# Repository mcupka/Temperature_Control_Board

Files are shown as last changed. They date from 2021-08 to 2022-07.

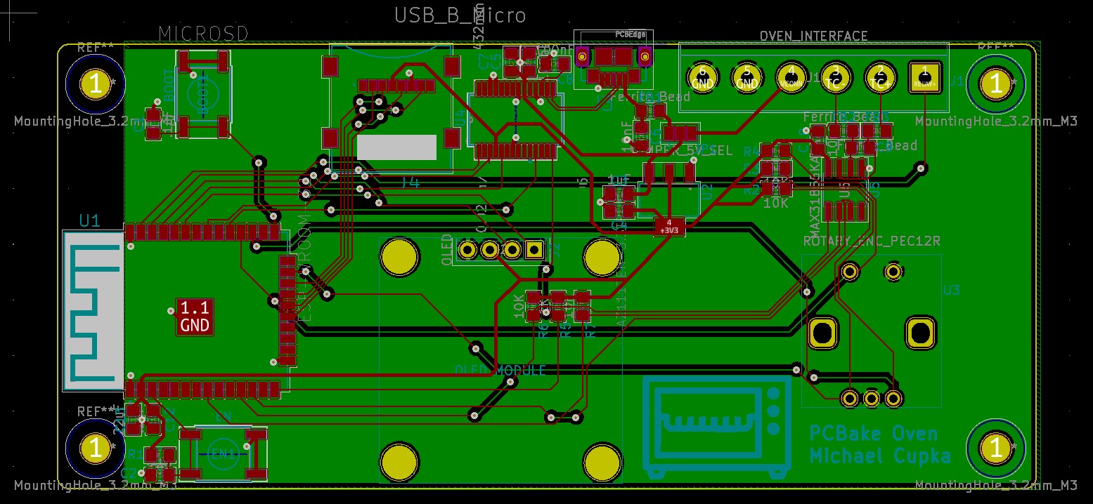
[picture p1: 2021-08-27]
images/v1_0/release_v1_0_pcb.jpg

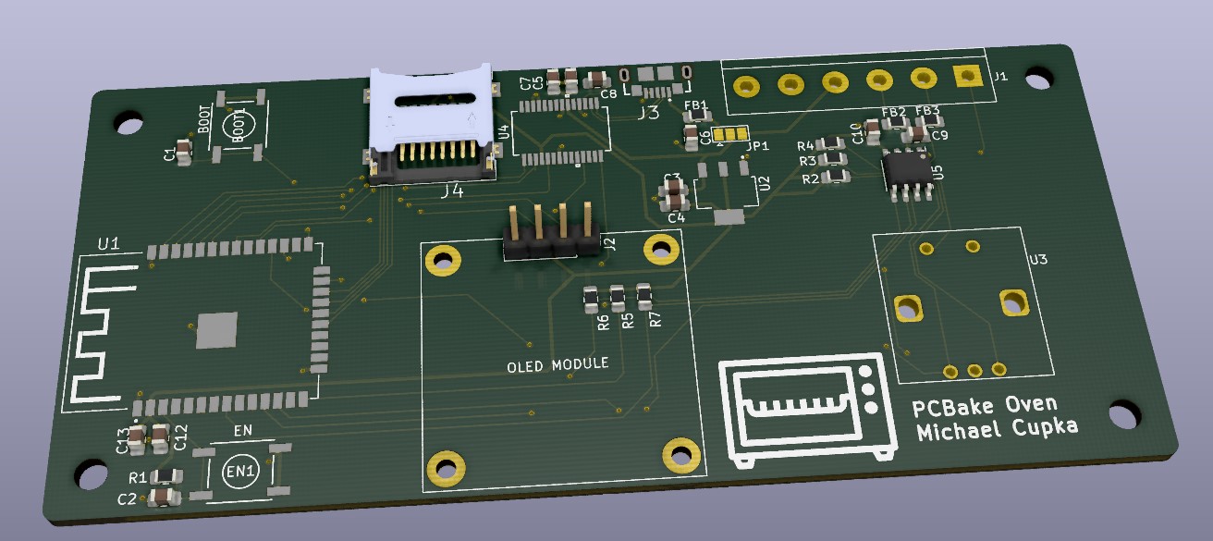
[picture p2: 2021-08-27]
images/v1_0/release_v1_0_render.jpg

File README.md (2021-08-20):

Temperature Control Board

This is a control board for a toaster oven reflow project. It will use the following major parts:

- ESP32 module for processing (wifi / bluetooth maybe?)
- MAX31855 to interface with the thermocouple
- SD Card interface
- I2C interface for OLED display
- UART for debug / programming (microusb?)
- Extra IOs and interfaces available for future uses of this board

Release V1.0 Images:

Release v1.0 PCB Release v1.0 Schematic

Release v1.0 PCB

Release v1.0 PCB Release v1.0 Render

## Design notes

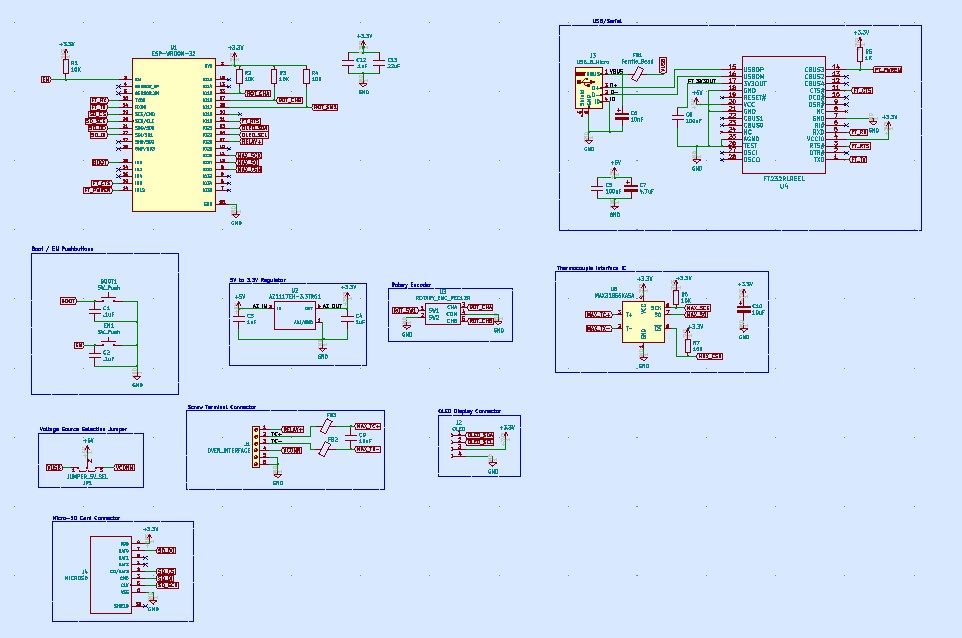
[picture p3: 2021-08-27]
images/v1_0/release_v1_0_sch.jpg

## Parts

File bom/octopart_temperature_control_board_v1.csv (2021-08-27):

Query | Qty | Manufacturer | MPN | Octopart URL | Part Description | Description | Schematic Reference | Internal Part Number | Lifecycle | Lead Time | RoHS | Total Qty (@ Batch Size: 1) | SKU | SKU | SKU | SKU | SKU | Packaging | Packaging | Packaging | Packaging | Packaging | Unit Price (@ Batch Size: 1) | Unit Price (@ Batch Size: 1) | Unit Price (@ Batch Size: 1) | Unit Price (@ Batch Size: 1) | Unit Price (@ Batch Size: 1) | In Stock | In Stock | In Stock | In Stock | In Stock | MOQ | MOQ | MOQ | MOQ | MOQ | URL | URL | URL | URL | URL | Distributor [Lowest Price (Selected)] | SKU [Lowest Price (Selected)] | Packaging [Lowest Price (Selected)] | Unit Price (@ Batch Size: 1) [Lowest Price (Selected)] | Line Total [Lowest Price (Selected)] | Batch Total [Lowest Price (Selected)] | In Stock [Lowest Price (Selected)] | MOQ [Lowest Price (Selected)] | URL [Lowest Price (Selected)] | Notes
 |  |  |  |  |  |  |  |  |  |  |  |  | Digi-Key | Mouser | Newark | Onlinecomponents.com | RS Components | Digi-Key | Mouser | Newark | Onlinecomponents.com | RS Components | Digi-Key | Mouser | Newark | Onlinecomponents.com | RS Components | Digi-Key | Mouser | Newark | Onlinecomponents.com | RS Components | Digi-Key | Mouser | Newark | Onlinecomponents.com | RS Components | Digi-Key | Mouser | Newark | Onlinecomponents.com | RS Components
AZ1117EH-3.3TRG1 | 1 | Diodes Inc. | AZ1117EH-3.3TRG1 | https://octopart.com/az1117eh-3.3trg1-diodes+inc.-49446529 | LDO Fixed Output Voltage Regulator LM3965S-3.3V, +3.3V, 1.5A, SOT223 /tape-2k5/ | 3.3V Regulator | U2 |  |  |  | Compliant | 1
PEC12R-4220F-S0024 | 1 | Bourns | PEC12R-4220F-S0024 | https://octopart.com/pec12r-4220f-s0024-bourns-26648369 | Incremental Encoder 24 PPR 2 Bit Quadrature 5VDC at 10 mA IP40 PCB Mount 100RPM | Rotary Encoder | U3 |  |  | 24w | Compliant | 1 | PEC12R-4220F-S0024-ND | 652-PEC12R-4220F-S24 | 53W9605 | PEC12R-4220F-S0024 | 7377773P | Tray | Tray |  | Bulk |  | 1.17 | 1.15 | 1.15 |  | 1.233 | 7680 | 22 | 51 | 1240 | 1 | 1 | 1 | 1 | 20 | 1 | https://octopart.com/click/track?country=US&ct=offers&ppid=26648369&sid=459&sig=0e801e8&vpid=93845225&ai4=706 | https://octopart.com/click/track?country=US&ct=offers&ppid=26648369&sid=2401&sig=09f0eeb&vpid=84631990&ai4=706 | https://octopart.com/click/track?country=US&ct=offers&ppid=26648369&sid=2402&sig=0076b96&vpid=96067648&ai4=706 | https://octopart.com/click/track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 | https://octopart.com/click/track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 | Newark | 53W9605 |  | 1.15 | 1.15 | 1.15 | 51 | 1 | https://octopart.com/click/track?country=US&ct=offers&ppid=26648369&sid=2402&sig=0076b96&vpid=96067648&ai4=706
OSTTC032162 | 2 | On Shore Technology | OSTTC032162 | https://octopart.com/osttc032162-on+shore+technology-309929 | Terminal Block Header 3 Position Top Screw 0.200" (5.08mm) PC Pins | Screw Terminal Block | J1 |  |  | 17w | Compliant | 2 | ED2610-ND |  |  |  |  | Bulk |  |  |  |  | 0.89 |  |  |  |  | 27826 |  |  |  |  | 1 |  |  |  |  | https://octopart.com/click/track?c=1&country=US&ct=offers&ppid=309929&sid=459&sig=040ab9c&vpid=1686177&ai4=706 |  |  |  |  | Digi-Key | ED2610-ND | Bulk | 0.89 | 1.78 | 1.78 | 27826 | 1 | https://octopart.com/click/track?c=1&country=US&ct=offers&ppid=309929&sid=459&sig=040ab9c&vpid=1686177&ai4=706
MEM2067-02-180-00-A | 1 | Global Connector Technology | MEM2067-02-180-00-A | https://octopart.com/mem2067-02-180-00-a-global+connector+technology-51853453 | 8 Contact Hinged SMT 1.8 mm Profile Micro SD Card (No Peg No Switch) | Micro-SD Card Connector | J4 |  |  |  | Non-Compliant | 1 |  |  | 87X8191 |  |  |  |  |  |  |  |  |  | 1.12 |  |  |  |  | 1000 |  |  |  |  | 1 |  |  |  |  | https://octopart.com/click/track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 |  |  | Newark | 87X8191 |  | 1.12 | 1.12 | 1.12 | 1000 | 1 | https://octopart.com/click/track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
FT232RL-REEL | 1 | FTDI | FT232RL-REEL | https://octopart.com/ft232rl-reel-ftdi-19172117 | USB Controller, 3MBd, USB2.0, 1.8 - 5.25 V, 28-Pin SSOP, USBmadeEZ-UART Series | USB to RS232 controller | U4 |  |  | 33w | Compliant | 1 | 768-1007-6-ND | 895-FT232RL | 91K9918 |  | 406580P | Custom Reel | Tape & Reel |  |  |  | 4.7 | 4.7 | 7.84 |  |  | 0 | 0 | 0 |  | 8387 | 1 | 1 | 1 |  | 20 | https://octopart.com/click/track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 | https://octopart.com/click/track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 | https://octopart.com/click/track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 |  | https://octopart.com/click/track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 | Digi-Key | 768-1007-6-ND | Custom Reel | 4.7 | 4.7 | 4.7 | 0 | 1 | https://octopart.com/click/track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
PTS645SL50SMTR92LFS | 2 | C&K Components | PTS645SL50SMTR92LFS | https://octopart.com/pts645sl50smtr92lfs-c%26k+components-55397153 | Switch Tactile N.O. SPST Round Button Gull Wing 0.05A 12VDC 100000Cycles 1.27N SMD T/R | Tactile Switch | BOOT1, EN1 |  |  | 30w | Compliant | 2 | CKN9088CT-ND | 611-PTS645SL50SMTR92 | 35AH5230 | PTS645SL50SMTR92LFS | 1359177 | Cut Tape | Tape & Reel |  | Bulk |  | 0.25 | 0.26 | 0.166 |  |  | 125100 | 22727 | 437 | 1800 | 1 | 1 | 1 | 1 | 1000 | 1000 | https://octopart.com/click/track?country=US&ct=offers&ppid=55397153&sid=459&sig=0bc7f49&vpid=76879289&ai4=706 | https://octopart.com/click/track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 | https://octopart.com/click/track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 | https://octopart.com/click/track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 | https://octopart.com/click/track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 | Newark | 35AH5230 |  | 0.166 | 0.332 | 0.332 | 437 | 1 | https://octopart.com/click/track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
USB3076-30-A | 1 | Global Connector Technology | USB3076-30-A | https://octopart.com/usb3076-30-a-global+connector+technology-21335114 | Conn Micro USB Type B RCP 2Power/3Signal POS 0.65mm Solder RA SMD 5 Terminal 1 Port T/R | Micro-USB Connector | J3 |  |  |  | Compliant | 1 |  |  | 73T7895 |  |  |  |  |  |  |  |  |  | 0.232 |  |  |  |  | 1341 |  |  |  |  | 1 |  |  |  |  | https://octopart.com/click/track?country=US&ct=offers&ppid=21335114&sid=2402&sig=0acd79c&vpid=44730736&ai4=706 |  |  | Newark | 73T7895 |  | 0.232 | 0.232 | 0.232 | 1341 | 1 | https://octopart.com/click/track?country=US&ct=offers&ppid=21335114&sid=2402&sig=0acd79c&vpid=44730736&ai4=706
ESP32-WROOM-32 | 1 | Espressif Systems | ESP32-WROOM-32 | https://octopart.com/esp32-wroom-32-espressif+systems-91025511 | Bluetooth and Wi-Fi Module 2.4GHz to 2.5GHz 2.7V to 3.6V 38-Pin SMD Module | ESP32 Microcontroller Module | U1 |  |  | 8w | Non-Compliant | 1 | 1904-1010-6-ND |  |  |  |  | Custom Reel |  |  |  |  | 0 |  |  |  |  | 0 |  |  |  |  | 1 |  |  |  |  | https://octopart.com/click/track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 |  |  |  |  | Digi-Key | 1904-1010-6-ND | Custom Reel | 0 | 0 | 0 | 0 | 1 | https://octopart.com/click/track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
MAX31855KASA+T | 1 | Maxim Integrated | MAX31855KASA+T | https://octopart.com/max31855kasa%2Bt-maxim+integrated-18998174 | MAX31855 Series 3.6V 900 uA 470.6 mW Thermocouple-to-Digital Converter - SOIC-8 | Thermocouple Interface IC | U5 |  | Production (Last Updated: 1 month ago) | 52w | Compliant | 1 | MAX31855KASA+TCT-ND | 700-MAX31855KASA+T | 73Y3353 |  | 1904615 | Cut Tape | Tape & Reel |  |  |  | 5.31 | 5.38 | 5.83 |  |  | 4633 | 7895 | 0 |  | 1 | 1 | 1 | 1 |  | 2500 | https://octopart.com/click/track?country=US&ct=offers&ppid=18998174&sid=459&sig=03a4b43&vpid=39491590&ai4=706 | https://octopart.com/click/track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 | https://octopart.com/click/track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 |  | https://octopart.com/click/track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 | Digi-Key | MAX31855KASA+TCT-ND | Cut Tape | 5.31 | 5.31 | 5.31 | 4633 | 1 | https://octopart.com/click/track?country=US&ct=offers&ppid=18998174&sid=459&sig=03a4b43&vpid=39491590&ai4=706
22-28-4360 | 1 | Molex | 22-28-4360 | https://octopart.com/22-28-4360-molex-278204 | KK 254 Breakaway Header, Vertical, 36 Circuits, Tin (Sn) Plating, Mating Pin Length 6.09mm | .1in Pin Header | JP1, J2 |  | Production (Last Updated: 1 year ago) | 14w | Compliant | 1 | WM50014-36-ND | 538-22-28-4360 | 56H2242 | 22-28-4360 | 8967364 | Bulk | Bulk |  | Bulk |  | 1.19 | 1.14 | 1.16 |  |  | 0 | 3393 | 135 | 166 | 1 | 1 | 1 | 1 | 50 | 5 | https://octopart.com/click/track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 | https://octopart.com/click/track?country=US&ct=offers&ppid=278204&sid=2401&sig=07c09e7&vpid=37607153&ai4=706 | https://octopart.com/click/track?country=US&ct=offers&ppid=278204&sid=2402&sig=0a2989d&vpid=2996742&ai4=706 | https://octopart.com/click/track?country=US&ct=offers&ppid=278204&sid=2429&sig=03aef65&vpid=733257100&ai4=706 | https://octopart.com/click/track?country=US&ct=offers&ppid=278204&sid=10022&sig=06d0da3&vpid=575614163&ai4=706 | Mouser | 538-22-28-4360 | Bulk | 1.14 | 1.14 | 1.14 | 3393 | 1 | https://octopart.com/click/track?country=US&ct=offers&ppid=278204&sid=2401&sig=07c09e7&vpid=37607153&ai4=706
STC02SYAN | 1 | Sullins | STC02SYAN | https://octopart.com/stc02syan-sullins-299958 | 2 C, Closed Top, .100" CC; No Mounting, 105 C, PBT; Phos Bronze, 100u" Matte Tin | 1.in Pin Jumper | JP1 |  |  | 5w | Compliant | 1 | S9000-ND |  |  |  |  | Bulk |  |  |  |  | 0.1 |  |  |  |  | 519275 |  |  |  |  | 1 |  |  |  |  | https://octopart.com/click/track?country=US&ct=offers&ppid=299958&sid=459&sig=0070ac5&vpid=1221941&ai4=706 |  |  |  |  | Digi-Key | S9000-ND | Bulk | 0.1 | 0.1 | 0.1 | 519275 | 1 | https://octopart.com/click/track?country=US&ct=offers&ppid=299958&sid=459&sig=0070ac5&vpid=1221941&ai4=706
BLM21PG221SN1D | 3 | Murata | BLM21PG221SN1D | https://octopart.com/blm21pg221sn1d-murata-368353 | Ferrite Beads Multi-Layer 220Ohm 25% 100MHz 2A 45mOhm DCR 0805 Paper T/R | Ferrite Bead | FB1, FB2, FB3 |  | Production (Last Updated: 1 month ago) | 21w | Compliant | 3 | 490-1054-1-ND | 81-BLM21P221SG | 73M9167 |  | 7241532P | Cut Tape | Tape & Reel |  |  |  | 0.11 | 0.1 | 0.15 |  |  | 62249 | 0 | 17183 |  | 1 | 1 | 1 | 1 |  | 25 | https://octopart.com/click/track?country=US&ct=offers&ppid=368353&sid=459&sig=0703c49&vpid=2086687&ai4=706 | https://octopart.com/click/track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 | https://octopart.com/click/track?country=US&ct=offers&ppid=368353&sid=2402&sig=0465cb4&vpid=11380727&ai4=706 |  | https://octopart.com/click/track?country=US&ct=offers&ppid=368353&sid=10022&sig=01d5a40&vpid=660716784&ai4=706 | Mouser | 81-BLM21P221SG | Tape & Reel | 0.1 | 0.30000000000000004 | 0.30000000000000004 | 0 | 1 | https://octopart.com/click/track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
08055C104KAT2A | 5 | AVX | 08055C104KAT2A | https://octopart.com/08055c104kat2a-avx-55386349 | Capacitor, Ceramic; 0.1UF; Chip; Case 0805; +/-10%; 50WVDC; SMD; X7R; 2.5% Df; 0.037IN. , | Capacitor, .1 uF | C1, C2, C5, C8, C12 |  | Production (Last Updated: 2 years ago) | 34w | Compliant | 5 | 478-1395-1-ND | 581-08055C104K | 27C8438 |  | 4646688 | Cut Tape | Tape & Reel |  |  |  | 0.1 | 0.16 | 0.192 |  |  | 6564853 | 2547831 | 249789 |  | 1 | 1 | 1 | 1 |  | 50 | https://octopart.com/click/track?country=US&ct=offers&ppid=55386349&sid=459&sig=01b1845&vpid=187969502&ai4=706 | https://octopart.com/click/track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 | https://octopart.com/click/track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 |  | https://octopart.com/click/track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 | Digi-Key | 478-1395-1-ND | Cut Tape | 0.1 | 0.5 | 0.5 | 6564853 | 1 | https://octopart.com/click/track?country=US&ct=offers&ppid=55386349&sid=459&sig=01b1845&vpid=187969502&ai4=706
CC0805KKX7R7BB105 | 2 | Yageo | CC0805KKX7R7BB105 | https://octopart.com/cc0805kkx7r7bb105-yageo-8376555 | 0805 1 uF 16 V ±10 % Tolerance X7R SMT Multilayer Ceramic Capacitor | Capacitor, 1 uF | C3, C4 |  |  | 24w | Compliant | 2 | 311-1365-1-ND | 603-CC805KKX7R7BB105 | 68R4880 |  | 1988098 | Cut Tape | Tape & Reel |  |  |  | 0.16 | 0.24 | 0.288 |  |  | 649716 | 4808 | 1152 |  | 2300 | 1 | 1 | 1 |  | 100 | https://octopart.com/click/track?country=US&ct=offers&ppid=8376555&sid=459&sig=0a46e44&vpid=34209660&ai4=706 | https://octopart.com/click/track?country=US&ct=offers&ppid=8376555&sid=2401&sig=0d84cf8&vpid=64034544&ai4=706 | https://octopart.com/click/track?country=US&ct=offers&ppid=8376555&sid=2402&sig=0aba7d4&vpid=21911110&ai4=706 |  | https://octopart.com/click/track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 | Digi-Key | 311-1365-1-ND | Cut Tape | 0.16 | 0.32 | 0.32 | 649716 | 1 | https://octopart.com/click/track?country=US&ct=offers&ppid=8376555&sid=459&sig=0a46e44&vpid=34209660&ai4=706
08055C103KAT2A | 2 | AVX | 08055C103KAT2A | https://octopart.com/08055c103kat2a-avx-55388009 | 0805 10 nF 50V ±10% Tolerance X7R Surface Mount Multilayer Ceramic Capacitor | Capacitor, 10 nF | C6, C9 |  | Production (Last Updated: 2 years ago) | 18w | Compliant | 2 | 478-1383-1-ND | 581-08055C103K | 19C6332 |  | 1359020 | Cut Tape | Tape & Reel |  |  |  | 0.1 | 0.14 | 0.168 |  |  | 971967 | 669456 | 110632 |  | 1 | 1 | 1 | 1 |  | 200 | https://octopart.com/click/track?country=US&ct=offers&ppid=55388009&sid=459&sig=0b95265&vpid=187969463&ai4=706 | https://octopart.com/click/track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 | https://octopart.com/click/track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 |  | https://octopart.com/click/track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 | Digi-Key | 478-1383-1-ND | Cut Tape | 0.1 | 0.2 | 0.2 | 971967 | 1 | https://octopart.com/click/track?country=US&ct=offers&ppid=55388009&sid=459&sig=0b95265&vpid=187969463&ai4=706
C0805C226M9PACTU | 1 | KEMET | C0805C226M9PACTU | https://octopart.com/c0805c226m9pactu-kemet-105756 | Multilayer Ceramic Capacitors MLCC - SMD/SMT 22uF 6.3V 0805 RoHS | Capacitor, 22 uF | C13 |  |  | 52w | Compliant | 1 | 399-4696-1-ND | 80-C0805C226M9P | 70K9142 | C0805C226M9PACTU | 6911177 | Cut Tape | Tape & Reel |  | Bulk |  | 0.22 | 1.34 | 0.755 |  |  | 2161537 | 312914 | 5607 | 0 | 1 | 1 | 1 | 1 | 2500 | 25 | https://octopart.com/click/track?country=US&ct=offers&ppid=105756&sid=459&sig=07c97ad&vpid=1861811&ai4=706 | https://octopart.com/click/track?country=US&ct=offers&ppid=105756&sid=2401&sig=05dfd3b&vpid=37686783&ai4=706 | https://octopart.com/click/track?country=US&ct=offers&ppid=105756&sid=2402&sig=0dd61dd&vpid=16452457&ai4=706 | https://octopart.com/click/track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 | https://octopart.com/click/track?country=US&ct=offers&ppid=105756&sid=10022&sig=0fd2a39&vpid=575542129&ai4=706 | Digi-Key | 399-4696-1-ND | Cut Tape | 0.22 | 0.22 | 0.22 | 2161537 | 1 | https://octopart.com/click/track?country=US&ct=offers&ppid=105756&sid=459&sig=07c97ad&vpid=1861811&ai4=706
CL21B475KOFNNNE | 1 | Samsung | CL21B475KOFNNNE | https://octopart.com/cl21b475kofnnne-samsung-19832443 | Cap Ceramic 4.7uF 16V X7R 10% SMD 0805 125°C Emboss T/R | Capacitor, 4.7 uF | C7 |  | Production (Last Updated: 1 year ago) | 28w | Compliant | 1 | 1276-2873-1-ND | 187-CL21B475KOFNNNE | 82AC9465 |  |  | Cut Tape | Tape & Reel |  |  |  | 0.28 | 0.29 | 0.35 |  |  | 196685 | 3572 | 32316 |  |  | 1 | 1 | 1 |  |  | https://octopart.com/click/track?country=US&ct=offers&ppid=19832443&sid=459&sig=0fea03e&vpid=72526665&ai4=706 | https://octopart.com/click/track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 | https://octopart.com/click/track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 |  |  | Digi-Key | 1276-2873-1-ND | Cut Tape | 0.28 | 0.28 | 0.28 | 196685 | 1 | https://octopart.com/click/track?country=US&ct=offers&ppid=19832443&sid=459&sig=0fea03e&vpid=72526665&ai4=706
CC0805KKX5R6BB106 | 1 | Yageo | CC0805KKX5R6BB106 | https://octopart.com/cc0805kkx5r6bb106-yageo-42244639 | 0805 10 uF 10 V ±10 % Tolerance X5R SMT Multilayer Ceramic Capacitor | Capacitor, 10 uF | C10 |  |  | 24w | Compliant | 1 | 311-1460-1-ND | 603-CC805KKX5R6BB106 | 98K7062 |  | 1988064P | Cut Tape | Tape & Reel |  |  |  | 0.44 | 0.45 |  |  |  | 98912 | 27652 | 2619 |  | 1700 | 1 | 1 | 5 |  | 250 | https://octopart.com/click/track?country=US&ct=offers&ppid=42244639&sid=459&sig=0700cd2&vpid=115141243&ai4=706 | https://octopart.com/click/track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 | https://octopart.com/click/track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 |  | https://octopart.com/click/track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 | Digi-Key | 311-1460-1-ND | Cut Tape | 0.44 | 0.44 | 0.44 | 98912 | 1 | https://octopart.com/click/track?country=US&ct=offers&ppid=42244639&sid=459&sig=0700cd2&vpid=115141243&ai4=706
RC0805JR-071KL | 1 | Yageo | RC0805JR-071KL | https://octopart.com/rc0805jr-071kl-yageo-40025580 | Res Thick Film 0805 1K Ohm 5% 0.125W(1/8W) ±100ppm/°C Pad SMD T/R | Resistor, 1K Ohm | R5 |  |  | 30w | Compliant | 1 | 311-1.0KARCT-ND | 603-RC0805JR-071KL | 68R0253 |  | 1995762P | Cut Tape | Tape & Reel |  |  |  | 0.1 | 0.1 | 0.1 |  |  | 1127297 | 0 | 658 |  | 113700 | 1 | 1 | 1 |  | 1000 | https://octopart.com/click/track?country=US&ct=offers&ppid=40025580&sid=459&sig=06a17fe&vpid=114983378&ai4=706 | https://octopart.com/click/track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 | https://octopart.com/click/track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 |  | https://octopart.com/click/track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 | Digi-Key | 311-1.0KARCT-ND | Cut Tape | 0.1 | 0.1 | 0.1 | 1127297 | 1 | https://octopart.com/click/track?country=US&ct=offers&ppid=40025580&sid=459&sig=06a17fe&vpid=114983378&ai4=706
RC0805FR-0710KL | 6 | Yageo | RC0805FR-0710KL | https://octopart.com/rc0805fr-0710kl-yageo-40301103 | Res Thick Film 0805 10K Ohm 1% 0.125W(1/8W) +/-100ppm/C Epoxy Pad SMD T/R | Resistor, 10K Ohm | R1, R2, R3, R4, R6, R7 |  |  | 20w | Compliant | 6 | 311-10.0KCRCT-ND | 603-RC0805FR-0710KL | 05M4535 |  | 6185163 | Cut Tape | Tape & Reel |  |  |  | 0.1 | 0.1 |  |  |  | 8367698 | 1220267 | 371303 |  | 1 | 1 | 1 | 10 |  | 5000 | https://octopart.com/click/track?country=US&ct=offers&ppid=40301103&sid=459&sig=02e3450&vpid=114983200&ai4=706 | https://octopart.com/click/track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 | https://octopart.com/click/track?country=US&ct=offers&ppid=40301103&sid=2402&sig=0add978&vpid=20052559&ai4=706 |  | https://octopart.com/click/track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 | Digi-Key | 311-10.0KCRCT-ND | Cut Tape | 0.1 | 0.6000000000000001 | 0.6000000000000001 | 8367698 | 1 | https://octopart.com/click/track?country=US&ct=offers&ppid=40301103&sid=459&sig=02e3450&vpid=114983200&ai4=706

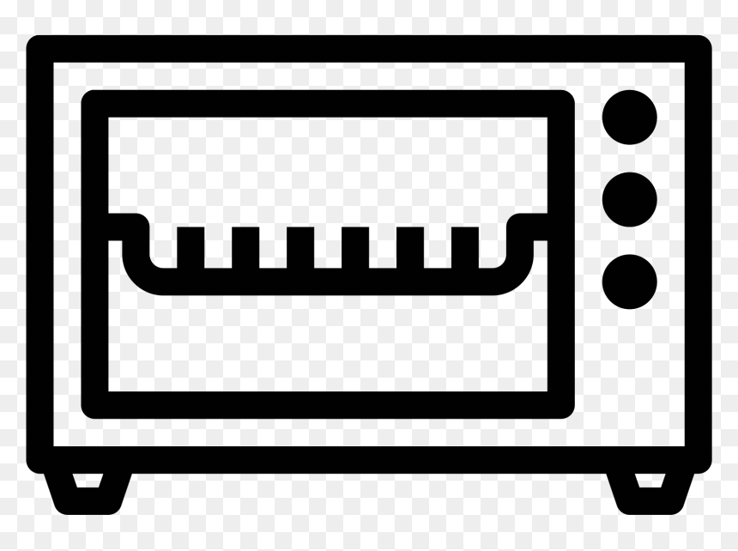
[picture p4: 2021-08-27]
parts/art/183-1839335_oven-clipart-bread-oven-toaster-oven-clip-art.png

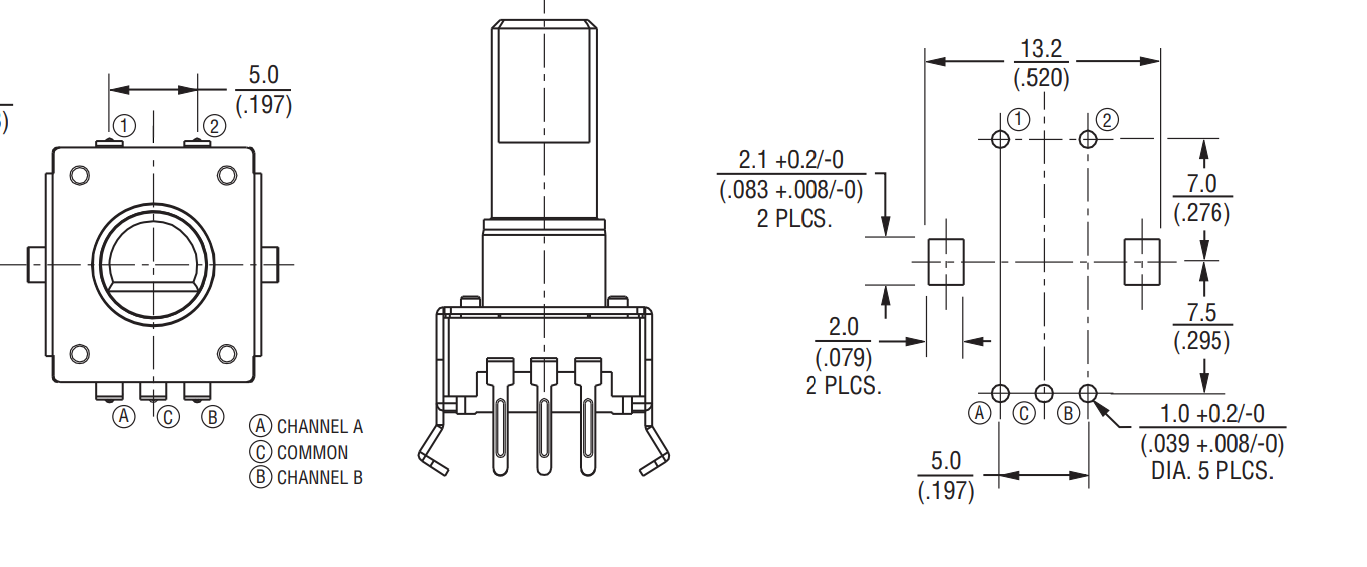
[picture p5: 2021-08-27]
parts/rotary_encoder/references/Capture.PNG

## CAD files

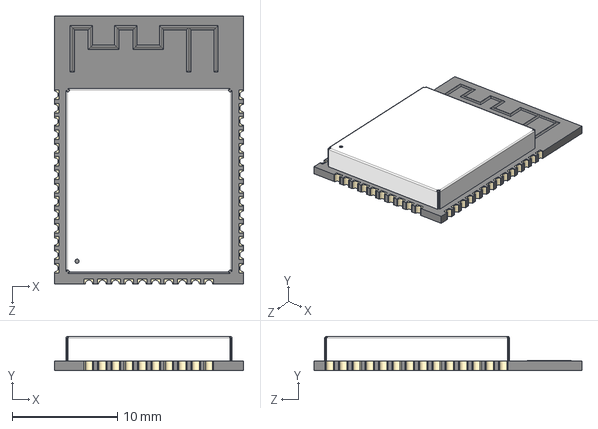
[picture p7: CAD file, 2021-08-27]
parts/esp32/ESP-WROOM-32.step
18.0 x 3.25 x 25.5 mm

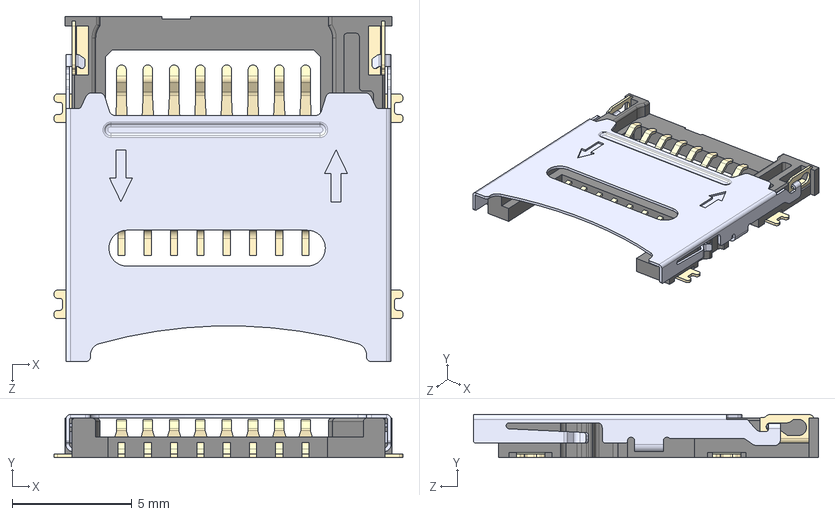
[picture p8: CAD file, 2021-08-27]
parts/microsd_connector/MEM2067-02-180-00-A_REVB.step
14.6 x 1.80 x 14.5 mm

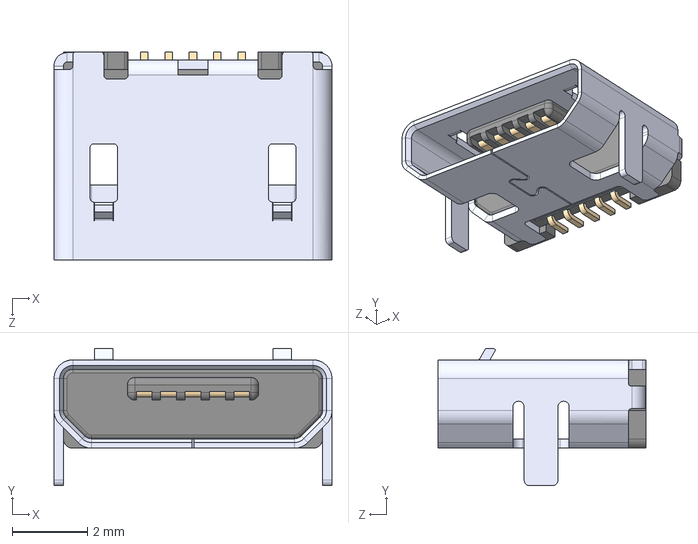
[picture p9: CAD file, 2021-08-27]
parts/usb_connector/USB3076-XX-X_REVC.step
7.40 x 3.66 x 5.55 mm

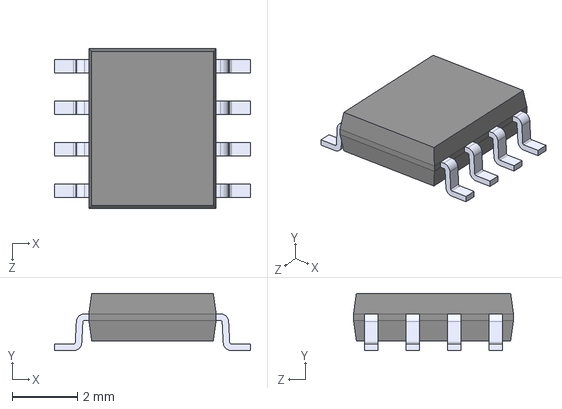
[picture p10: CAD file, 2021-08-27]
parts/thermocouple_controller/MAX31855KASA_.step
6.00 x 1.75 x 4.90 mm

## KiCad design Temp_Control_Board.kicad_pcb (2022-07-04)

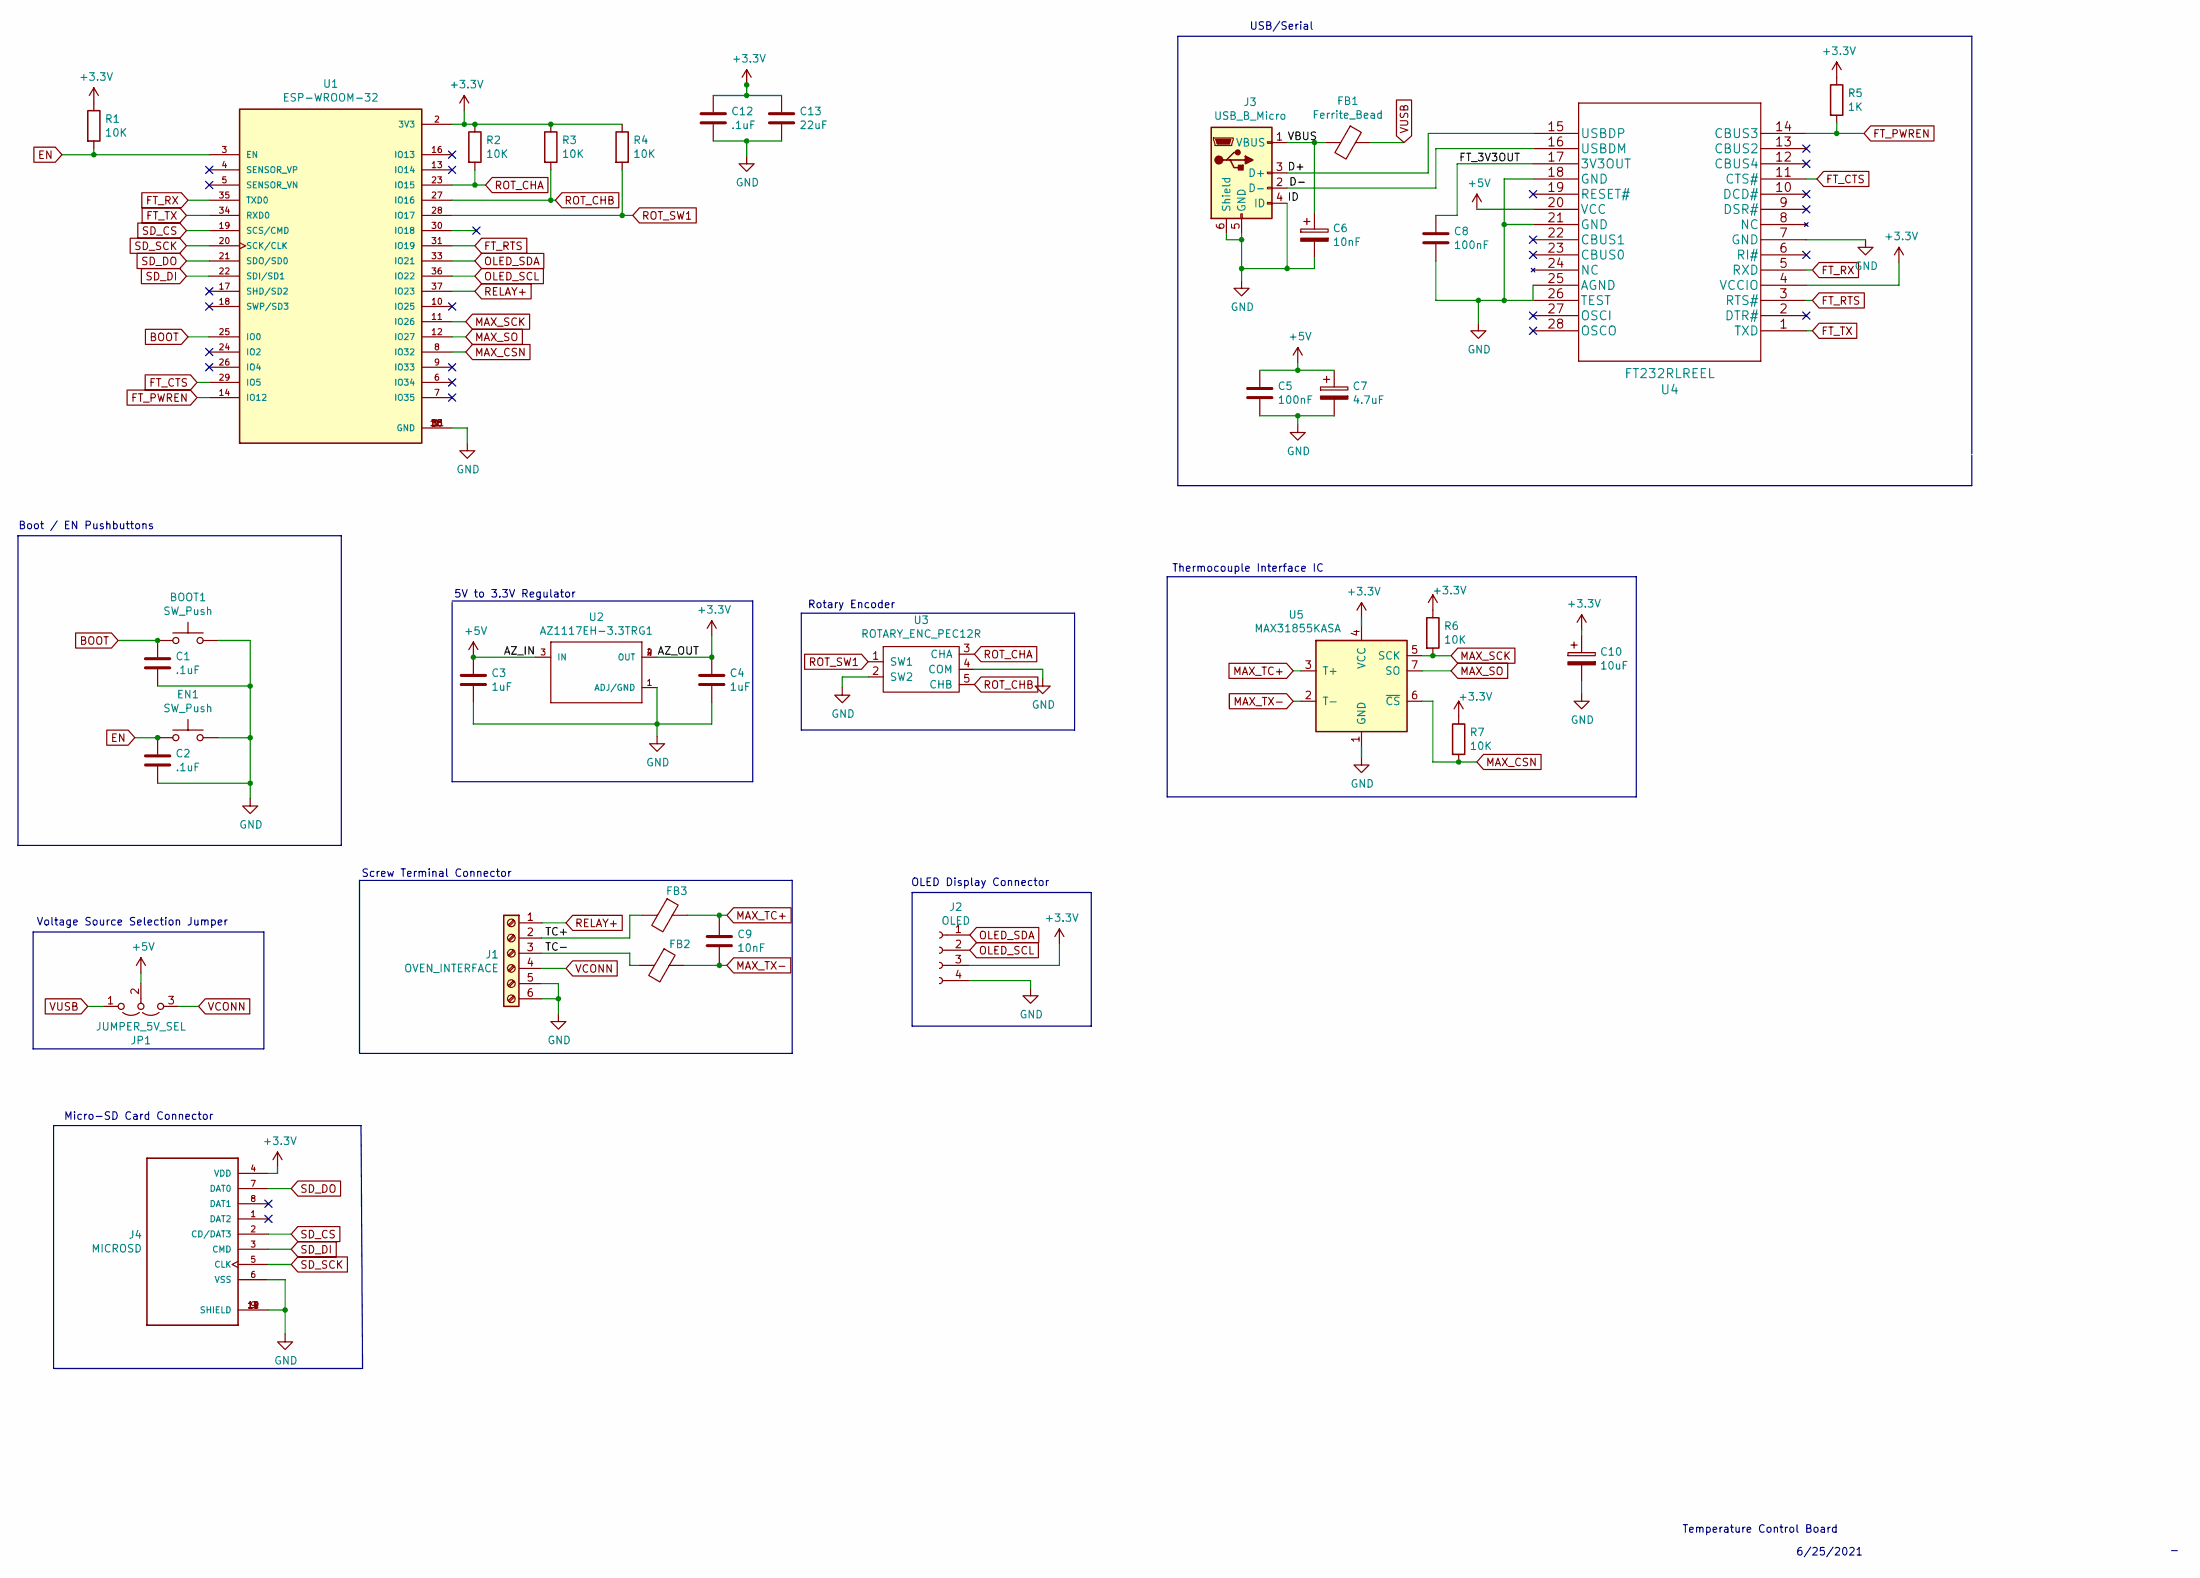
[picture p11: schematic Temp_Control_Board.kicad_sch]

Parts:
BOOT1: SW_Push; PTS645SK43SMTR92LF-CONNECTED
C1, C2, C12: .1uF; C_0805_2012Metric_Pad1.15x1.40mm_HandSolder
C3, C4: 1uF; C_0805_2012Metric_Pad1.15x1.40mm_HandSolder
C5, C8: 100nF; C_0805_2012Metric_Pad1.15x1.40mm_HandSolder
C6, C9: 10nF; C_0805_2012Metric_Pad1.15x1.40mm_HandSolder
C7: 4.7uF; C_0805_2012Metric_Pad1.15x1.40mm_HandSolder
C10: 10uF; C_0805_2012Metric_Pad1.15x1.40mm_HandSolder
C13: 22uF; C_0805_2012Metric_Pad1.15x1.40mm_HandSolder
EN1: SW_Push; PTS645SK43SMTR92LF-CONNECTED
FB1, FB2, FB3: Ferrite_Bead; R_0805_2012Metric_Pad1.15x1.40mm_HandSolder
J1: OVEN_INTERFACE; TerminalBlock_bornier-6_P5.08mm
J2: OLED; OLED_1MIL_HEADER_WHOLES
J3: USB_B_Micro
J4: MICROSD; GCT_MEM2067-02-180-00-A_REVB
JP1: JUMPER_5V_SEL; SolderJumper-3_P1.3mm_Open_Pad1.0x1.5mm
R1, R2, R3, R4, R6, R7: 10K; R_0805_2012Metric_Pad1.15x1.40mm_HandSolder
R5: 1K; R_0805_2012Metric_Pad1.15x1.40mm_HandSolder
U1: ESP-WROOM-32
U2: AZ1117EH-3.3TRG1; SOT230P700X180-4N
U3: ROTARY_ENC_PEC12R
U4: FT232RLREEL
U5: MAX31855KASA; SOIC-8_3.9x4.9mm_P1.27mm

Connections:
+3V3: C4.1, C10.1, C12.1, C13.1, J2.3, J4.4 (VDD), R1.1, R2.1, R3.1, R4.1, R5.1, R6.1, R7.1, U1.2 (3V3), U2.2 (OUT), U2.4 (OUT), U4.4 (VCCIO), U5.4 (VCC)
+5V: C3.1, C5.1, C7.1, JP1.2 (C), U2.3 (IN), U4.20 (VCC)
/D+: J3.3 (D+), U4.15 (USBDP)
/D-: J3.2 (D-), U4.16 (USBDM)
/FT_3V3OUT: C8.1, U4.17 (3V3OUT)
/TC+: FB3.2, J1.2
/TC-: FB2.2, J1.3
/VBUS: C6.1, FB1.2, J3.1 (VBUS)
BOOT: BOOT1.1, C1.1, U1.25 (IO0)
EN: C2.1, EN1.1, R1.2, U1.3 (EN)
FT_CTS: U1.29 (IO5), U4.11 (CTS#)
FT_PWREN: R5.2, U1.14 (IO12), U4.14 (CBUS3)
FT_RTS: U1.31 (IO19), U4.3 (RTS#)
FT_RX: U1.35 (TXD0), U4.5 (RXD)
FT_TX: U1.34 (RXD0), U4.1 (TXD)
GND: BOOT1.2, C1.2, C2.2, C3.2, C4.2, C5.2, C6.2, C7.2, C8.2, C10.2, C12.2, C13.2, EN1.2, J1.5, J1.6, J2.4, J3.4 (ID), J3.5 (GND), J3.6 (Shield), J4.6 (VSS), J4.9 (SHIELD), J4.10 (SHIELD), J4.11 (SHIELD), J4.12 (SHIELD), U1.1 (GND), U1.1.1 (GND), U1.15 (GND), U1.38 (GND), U2.1 (ADJ/GND), U3.2 (SW2), U3.4 (COM), U4.7 (GND), U4.18 (GND), U4.21 (GND), U4.25 (AGND), U4.26 (TEST), U5.1 (GND)
MAX_CSN: R7.2, U1.8 (IO32), U5.6 (~CS)
MAX_SCK: R6.2, U1.11 (IO26), U5.5 (SCK)
MAX_SO: U1.12 (IO27), U5.7 (SO)
MAX_TC+: C9.1, FB3.1, U5.3 (T+)
MAX_TX-: C9.2, FB2.1, U5.2 (T-)
OLED_SCL: J2.2, U1.36 (IO22)
OLED_SDA: J2.1, U1.33 (IO21)
RELAY+: J1.1, U1.37 (IO23)
ROT_CHA: R2.2, U1.23 (IO15), U3.3 (CHA)
ROT_CHB: R3.2, U1.27 (IO16), U3.5 (CHB)
ROT_SW1: R4.2, U1.28 (IO17), U3.1 (SW1)
SD_CS: J4.2 (CD/DAT3), U1.19 (SCS/CMD)
SD_DI: J4.3 (CMD), U1.22 (SDI/SD1)
SD_DO: J4.7 (DAT0), U1.21 (SDO/SD0)
SD_SCK: J4.5 (CLK), U1.20 (SCK/CLK)
VCONN: J1.4, JP1.3 (B)
VUSB: FB1.1, JP1.1 (A)

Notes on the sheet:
Screw Terminal Connector
Thermocouple Interface IC
6/25/2021
Micro-SD Card Connector
OLED Display Connector
Voltage Source Selection Jumper
USB/Serial
5V to 3.3V Regulator
Temperature Control Board
Boot / EN Pushbuttons
Rotary Encoder

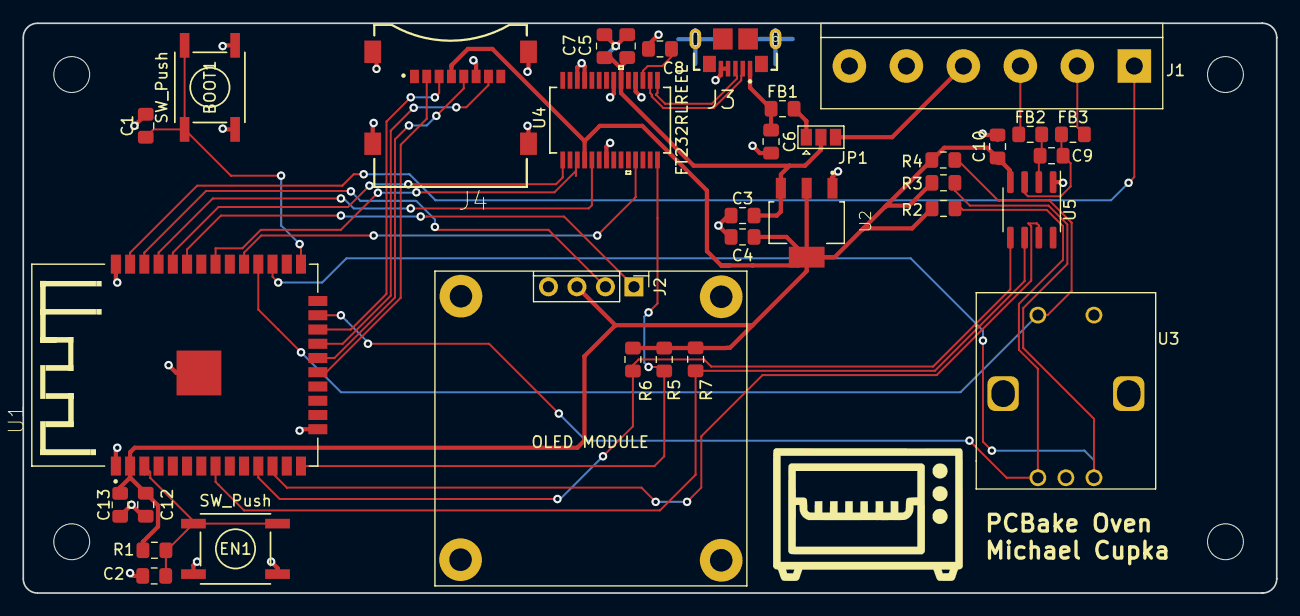
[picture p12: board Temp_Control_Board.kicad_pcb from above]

Board: 2 copper layers, 111.8 x 50.8 mm, 34 parts (0 on the bottom side), 33 nets.

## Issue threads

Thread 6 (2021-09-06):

Tactile switches have wrong pairs of pins connected

mcupka, 2021-09-06:
The tactile switch footprint shows the wrong sets of pins connected. This was remedied during assembly by clipping two diagonally opposite pins off of the switches.

Closed 2022-07-04.

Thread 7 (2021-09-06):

Change SD Card pins

mcupka, 2021-09-06:
The micro sd card is connected to pins "SCK/CLK", "SDO/SD0", "SDI/SD1", and "SCS/CMD." The datasheet mentions that these pins are connected to the internal SPI flash and are not recommended for other uses. It appears that the ESP32 has trouble booting from flash when an sd card is present on these pins. These sd card pins should be moved to a different SPI bus on the ESP32.

mcupka, 2023-03-18:
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
From ESP-WROOM-32 Datasheet

mcupka, 2023-03-18:
Deciding to use VSPI (SPI3) for the SD card:
MOSI = IO23
MISO = IO19
CLK = IO18
CS = IO5

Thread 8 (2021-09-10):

ESP32 Doesn't Load Firmware On Power-Up. Require Reset via EN Button

mcupka, 2021-09-10:
The ESP32 module does not load the firmware upon power-up. It requires a reset via the EN pin before it will load firmware. This is not the behavior seen on devkits that use the same module. Currently unsure if this issue exists when powered via screw terminal connector.

Found on V1.0 hardware

mcupka, 2022-07-05:
https://dl.espressif.com/dl/schematics/esp32_devkitc_v4-sch.pdf
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

See ESP32 development board schematic. I need to add DTR / RTS circuit for auto reset on program via serial.

mcupka, 2022-07-09:
I realized the dev board that I based some of this design on actually has two .1uf caps between EN and GND. I only have one. Adding a capacitor in parallel resolved the problem.

Need to do some more investigating to determine correct capacitance value that resolves the issue but isn't too large.

mcupka, 2022-07-10:
adding another .1uF did not resolve the issue. Neither did adding .22uF. I ended up adding 1uF, for a total of 1.1uF of capacitance. That seems to have resolved this issue. I am not sure why I need so much more capacitance than what the dev board uses. I may investigate further.

Add another capacitor or increase capacitance of the capacitor between EN and GND to 1uF to close this issue.

mcupka, 2022-07-10:
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

This note from the ESP-WROOM-32 datasheet does suggest 1uF for the power-on reset circuit, at least as a rule of thumb.

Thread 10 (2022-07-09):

Add circuit to allow serial reset / put ESP32 in firmware download mode

mcupka, 2022-07-09:
https://dl.espressif.com/dl/schematics/esp32_devkitc_v4-sch.pdf
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

See ESP32 development board schematic. I need to add DTR / RTS circuit for auto reset on program via serial.

Without this circuit, a manual reset is required each time the esp32 gets programmed.

I modified a V1 board, adding this circuit in and tested it. The board resets and boots up in programming mode correctly when ESP IDF's program script is called. Still needs added to the design in KiCAD to close out this issue.

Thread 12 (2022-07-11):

Add LEDs

mcupka, 2022-07-11:
There are no LEDs on the board. It would be nice to have a power indicator LED and an "Oven On" indicator.

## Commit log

2021-04-15 project: Initial commit sch: Initial commit pcb: Initial commit syms: Initial commit foots: Initial commit
    [Temp_Control_Board.kicad_pcb, Temp_Control_Board.sch]
2021-06-26 sch: First revision completed pcb: Footprints completed, first placement of components done. No routing.
    [Temp_Control_Board.kicad_pcb, Temp_Control_Board.sch]
2021-06-26 pro: set track widths
    pcb: routed power and ground
    [Temp_Control_Board.kicad_pcb]
2021-07-06 ORD airport
    [Temp_Control_Board.kicad_pcb, Temp_Control_Board.sch]
2021-07-06 After airport. Routed, needs touching up.
    [Temp_Control_Board.kicad_pcb, Temp_Control_Board.sch]
2021-08-20 pcb: Finished Routing
    -Touched up some traces
    -Made silkscreen presentable
    [Temp_Control_Board.kicad_pcb]
2021-08-27 git: added parts, gerbers, images, bom to git
    [ESP-WROOM-32.step, MAX31855KASA_.step, MEM2067-02-180-00-A_REVB.step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]
2022-07-04 proj: Updated to KiCAD 6
    - removed old files with KiCAD 5 extensions, added new files.
    - added footprint and symbol library tables
    - ignored autosave, cache, and backup data
    - added .gitignore
    [Temp_Control_Board.kicad_pcb, Temp_Control_Board.kicad_sch, Temp_Control_Board.sch]
2022-07-04 foots: Fixed tactile switch footprint and USB footprint
    - Tactile switch had wrong pins showing as connected internally
    - Changed through-hole pads for shield on USB connected to use actual oval pad instead of polygons
2022-07-04 pcb/shc: Fixed tactile switch routing, tied USB shield to GND
    [Temp_Control_Board.kicad_pcb, Temp_Control_Board.kicad_sch]
2022-07-11 parts: added esp32 datasheet
2023-03-18 Fixed BOOT / EN SWs ref designators
    - Fixes #4
    [Temp_Control_Board.kicad_sch]
2023-03-18 Changed all .1uF cap values to 100nF for consistency
    - Fixes #5
    [Temp_Control_Board.kicad_sch]

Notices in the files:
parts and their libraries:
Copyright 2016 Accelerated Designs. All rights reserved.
